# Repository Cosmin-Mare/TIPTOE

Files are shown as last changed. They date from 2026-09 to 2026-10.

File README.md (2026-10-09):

# TIPTOE

Multi-unit outdoor surveillance system with motion detection, night vision and long-range radio. Waterproof nodes watch an area, report events to a handheld over LoRa, and the handheld passes them to your phone.

One custom PCB for every unit · ESP32-S3 firmware (C++, PlatformIO) · Flutter companion app

| | |
|---|---|
| Hardware | [`PCB/`](PCB) schematics and gerbers, [`case/`](case) print files |
| Firmware and app | [`code/`](code) |
| Install the app | [Release v1.0.0](https://github.com/Cosmin-Mare/TIPTOE/releases/tag/v1.0.0) |
| Design log | [`JOURNAL.md`](JOURNAL.md) |

Top Right
Top Right white nocase

tiptoe_schematics_v5

## Overview

TIPTOE is a custom surveillance device built around the ESP32-S3. Units are deployed indoors or outdoors and talk to each other over LoRa for range and ESP-NOW when they're close. One unit is carried as a handheld; it collects events from the nodes and connects to a phone over BLE and Wi-Fi, where the app in [`code/app`](code/app) shows alerts and snapshots.

Every unit uses the same board. Whether it acts as a node or the handheld is set in firmware.

## Features

- **Motion detection** with a PIR sensor, which wakes the unit from sleep
- **Snapshots** from an OV3660 camera, with 940 nm IR LEDs for night vision
- **Audio** from a digital microphone
- **Qi wireless charging**, so the case can stay sealed, plus battery monitoring with a fuel gauge
- **Waterproof enclosure** for mounting on trees, walls or the ground (model in [`case/`](case))
- **No cloud or router needed:** unit-to-unit frames are AES-128-GCM encrypted and the phone link is passkey-paired BLE
- **Maintenance web page** on each node, with over-the-air firmware updates
- **App simulation mode**, so the whole flow can be tried without hardware

## Hardware

**Core**
- ESP32-S3-WROOM-1-N16R8 (main MCU)
- PCF8574T I/O expander (extra GPIO for peripherals)
**Power**
- BQ51013B Qi wireless receiver -> BQ25895 battery charger -> TPS63020 buck-boost -> ME6211 LDO
- MAX17048 fuel gauge for battery monitoring
**Sensing & I/O**
- OV3660 camera (DVP bus)
- ICS-43434 digital microphone
- HC-SR501 PIR motion sensor (boosted to 5V via AP3602AKTR-G1)
- IR LEDs for night vision (switched via AO3400A MOSFET)
- E22-900M22S LoRa module for long-range communication

## Project Status

The first PCB revision is in [`PCB/`](PCB), with firmware and the phone app in [`code/`](code). [`JOURNAL.md`](JOURNAL.md) was written in realtime throughout the design process and is left unpolished on purpose, so the raw process stays visible.

## Roadmap

- Assemble and test the first boards in person
- Finish the enclosure design and field-test it outdoors
- Publish a build write-up (Hack Club, Hackaday)

## Assembly

Getting from bare hardware to a running unit, end to end:

### 1. Fabricate & populate the board

- Gerbers: [`PCB/GERBER.zip`](PCB/GERBER.zip). Full BOM with LCSC part numbers: [`PCB/BOM.csv`](PCB/BOM.csv) (also below).
- Several parts are exposed-pad QFN/VQFN/WQFN packages (`BQ25895` WQFN-24, `TPS63020` VSON-14, `BQ51013B` VQFN-20, `MAX17048` TDFN-8) plus a 0.5 mm-pitch `ESP32-S3-WROOM-1` module and a 0.5 mm FPC camera connector — these need a stencil and reflow (or a hot-air rework station with real skill), not a hand iron alone. The straightforward path is to order PCB fab **and** SMT assembly together (e.g. JLCPCB PCBA) using the gerbers and the BOM/LCSC part numbers; leave through-hole parts (battery connector, PIR header, IR LEDs, buttons) for the assembly house to skip, and hand-solder those yourself afterward.
- You need at least 2 populated boards to test anything (one handheld + one node); the project targets 4 deployable units total. Every board is the *same* PCB — role is chosen later in firmware.

### 2. Connect the off-board modules

The BOM only places connectors on the PCB — three parts plug into those connectors and aren't optional for bring-up:

- **Camera** — an **OV3660** module, into the `Camera` FPC connector (`FPC-05F-24PH20`, 24-pin, 0.5mm pitch). Flip-lock connector: lift the tab, seat the FPC ribbon, press the tab back down.
- **PIR sensor** — an **HC-SR501** module, into the 3-pin `PIR` header (`HX PM2.54-1x3P`). Match GND/OUT/VCC to the silkscreen — it's a plain 2.54mm header, so it's easy to reverse.
- **Battery** — a single-cell Li-ion/LiPo pack terminated in a **JST-PH 2-pin** connector, into `BATTERY`. Mind polarity; the connector is keyed but double-check before first power-up. This is also how the board gets power to flash from, since USB-C is data-only (see below).

None of these three ship on the assembled board — order them separately and connect them before you flash.

### 3. Flash firmware

Each populated board runs the same firmware image. From [`code/`](code):

```bash
pip install platformio
cp src/common/secrets.example.h src/common/secrets.h     # then edit it
python3 -c "import os;print(', '.join('0x%02x'%b for b in os.urandom(16)))"   # paste into TIPTOE_NETWORK_KEY

pio run -t upload        # board must be running from battery or Qi (USB is data-only)
pio device monitor       # press a key within 3 s of boot for the console
```

- **USB-C is data-only by design** — the board must be powered from its battery or sitting on the Qi pad while you flash and use the console.
- From the console, set the role: `role handheld` on the unit you'll carry, `role node` (the default) on every outdoor unit. The unit reboots into the new role.
- Give each node a unique ID (`id 1`, `id 2`, …) from the console or its maintenance web UI.
- If a node is already asleep, hold BOOT, tap RST, release BOOT to force the ROM bootloader for the first flash. After that, firmware updates can go over Wi-Fi from the node's maintenance page.

Full firmware details, pin map, and console commands: [`code/README.md`](code/README.md).

### 4. First bring-up checklist

Run this on every board right after its first flash:

1. Power from battery, connect USB, reset, and press a key within 3 s → console.
2. `i2c` should list `0x20` (PCF8574), `0x36` (MAX17048), `0x6A` (BQ25895). The camera is on its own bus.
3. `selftest` checks the I/O expander, charger, fuel gauge, `VOUT` power-good, camera PID, mic level, IR pulse (watch through a phone camera — it's infrared), the SX1262 LoRa radio, flash, and PSRAM.
4. `status` shows charger state and the NTC reading; `chg` dumps the charger registers.
5. With the handheld powered on, `send` from a node should print `reply received`. `snap` runs a full event end-to-end.
6. `exit` → the node goes into normal sleep/wake operation.

### 5. Case & final assembly

- Case model: [`case/TIPTOE_Case.stp`](case/TIPTOE_Case.stp). Print or machine it, mount the populated PCB with the camera/PIR/IR LEDs aligned to the enclosure cutouts, and close it up for a node deployment.

### 6. Pair the app

- Install the app from [Release v1.0.0](https://github.com/Cosmin-Mare/TIPTOE/releases/tag/v1.0.0) (Android APK / iOS IPA), or run it from source — see [`code/app/README.md`](code/app/README.md).
- Pair with the handheld from the app. The BLE pairing PIN is `TIPTOE_BLE_PASSKEY`, set in the firmware's `secrets.h` — it isn't compiled into the app.
- No board yet? The app's first screen offers **Review with a simulation**, which walks through the whole flow without any hardware.

## Bill of Materials

Full sheet with LCSC links: [`PCB/BOM.csv`](PCB/BOM.csv).

| Qty | Designator(s) | Part / Value | LCSC # |
|---|---|---|---|
| 1 | 5VBoost | AP3602AKTR-G1 (PIR 5V boost) | [C460358](https://www.lcsc.com/product-detail/C460358.html) |
| 2 | ACM1, ACM2 | 22nF, C0603 | [C21122](https://www.lcsc.com/product-detail/C21122.html) |
| 1 | BATTERY | B2B-PH-K-S-GW (JST PH 2-pin) | [C5251182](https://www.lcsc.com/product-detail/C5251182.html) |
| 1 | Bat_Charger | BQ25895RTWT | [C2861263](https://www.lcsc.com/product-detail/C2861263.html) |
| 5 | BST1, BST2, C11, C12, C13 | 10nF, C0603 | [C100042](https://www.lcsc.com/product-detail/C100042.html) |
| 1 | Buck_Boost | TPS63020DSJR | [C15483](https://www.lcsc.com/product-detail/C15483.html) |
| 14 | C1, C5, C7, C15, C23, C25, C26, C27, C34, C36, C38, C39, DC1_ESP, DC2_ESP | 100nF, C0603 | [C14663](https://www.lcsc.com/product-detail/C14663.html) |
| 9 | C2, C3, C6, C9, C16, C17, C18, C21, C22 | 10uF, C1206 | [C9807](https://www.lcsc.com/product-detail/C9807.html) |
| 1 | C4 | 1nF, C0603 | [C106246](https://www.lcsc.com/product-detail/C106246.html) |
| 11 | C8, C19, C20, C24, C29, C30, C31, C32, C33, C35, C37 | 1uF, C1206 | [C90539](https://www.lcsc.com/product-detail/C90539.html) |
| 1 | C10 | 4.7uF, C1206 | [C29823](https://www.lcsc.com/product-detail/C29823.html) |
| 1 | C14 | 22uF, C1206 | [C5448922](https://www.lcsc.com/product-detail/C5448922.html) |
| 1 | C28 | 820pF, C0603 | [C107057](https://www.lcsc.com/product-detail/C107057.html) |
| 1 | Camera | FPC-05F-24PH20 (0.5mm 24P FPC) | [C2856805](https://www.lcsc.com/product-detail/C2856805.html) |
| 2 | CAM_SCL_PU, CAM_SDA_PU | 4.7kΩ, R0603 | [C23162](https://www.lcsc.com/product-detail/C23162.html) |
| 2 | CLAMP1, CLAMP2 | 470nF, C0603 | [C513577](https://www.lcsc.com/product-detail/C513577.html) |
| 1 | ESP | ESP32-S3-WROOM-1-N16R8 | [C2913202](https://www.lcsc.com/product-detail/C2913202.html) |
| 1 | Fuel_Gauge | MAX17048G+T10 | [C2682616](https://www.lcsc.com/product-detail/C2682616.html) |
| 2 | IO0, RST | TSD001A07526A (tactile button) | [C2888886](https://www.lcsc.com/product-detail/C2888886.html) |
| 1 | IOExpander | PCF8574T/TR | [C2987288](https://www.lcsc.com/product-detail/C2987288.html) |
| 4 | IR1, IR2, IR3, IR4 | IR333C-A (940nm IR LED) | [C5130](https://www.lcsc.com/product-detail/C5130.html) |
| 2 | L1, L2 | 2.2uH inductor | [C76855](https://www.lcsc.com/product-detail/C76855.html) |
| 1 | L3 | GZ1608D601TF (ferrite bead) | [C1002](https://www.lcsc.com/product-detail/C1002.html) |
| 1 | LORA | E22-900M22S (SX1262 LoRa module) | [C411293](https://www.lcsc.com/product-detail/C411293.html) |
| 1 | MIC | ICS-43434 (digital mic) | [C5656610](https://www.lcsc.com/product-detail/C5656610.html) |
| 1 | MSF_IR | AO3400A (IR LED MOSFET) | [C49195711](https://www.lcsc.com/product-detail/C49195711.html) |
| 1 | NTC | NCP18XH103F03RB (10k NTC) | [C13564](https://www.lcsc.com/product-detail/C13564.html) |
| 4 | PD_MSF, R11, R14, R18 | 100kΩ, R0603 | [C25803](https://www.lcsc.com/product-detail/C25803.html) |
| 1 | PIR | HX PM2.54-1x3P (PIR header) | [C22438153](https://www.lcsc.com/product-detail/C22438153.html) |
| 1 | QiCoil | 15uH Qi coil | [C3003210](https://www.lcsc.com/product-detail/C3003210.html) |
| 1 | QIPowerRec | BQ51013BRHLR | [C55663](https://www.lcsc.com/product-detail/C55663.html) |
| 11 | R1, R5, R6, R7, R8, R15, R16, R17, R21, RESETB_PU, R_IO0 | 10kΩ, R0603 | [C25804](https://www.lcsc.com/product-detail/C25804.html) |
| 4 | R2, R4, R9, R10 | 33Ω, R1206 | [C102174](https://www.lcsc.com/product-detail/C102174.html) |
| 1 | R3 | 68Ω, R0603 | [C27592](https://www.lcsc.com/product-detail/C27592.html) |
| 1 | R12 | 560kΩ, R0603 | [C23203](https://www.lcsc.com/product-detail/C23203.html) |
| 3 | R20, R24, R25 | 100Ω, R0603 | [C22775](https://www.lcsc.com/product-detail/C22775.html) |
| 1 | R22 | 470Ω, R0603 | [C23179](https://www.lcsc.com/product-detail/C23179.html) |
| 2 | R, R13 | 1kΩ, R0603 | [C126900](https://www.lcsc.com/product-detail/C126900.html) |
| 1 | RT1 | 5.1kΩ, R0603 | [C23186](https://www.lcsc.com/product-detail/C23186.html) |
| 1 | RT2 | 30kΩ, R0603 | [C100945](https://www.lcsc.com/product-detail/C100945.html) |
| 2 | R_CC5, R_CC6 | 5.1kΩ, R0402 | [C25905](https://www.lcsc.com/product-detail/C25905.html) |
| 2 | R_CC7, R_CC8 | 22Ω, R0402 | [C25092](https://www.lcsc.com/product-detail/C25092.html) |
| 1 | U4 | 47nF, C0805 | [C107154](https://www.lcsc.com/product-detail/C107154.html) |
| 1 | USBC | TYPE-C-31-M-12 (USB-C receptacle) | [C165948](https://www.lcsc.com/product-detail/C165948.html) |
| 1 | Voltage_Reg | ME6211C33M5G-N (3.3V LDO) | [C82942](https://www.lcsc.com/product-detail/C82942.html) |
| 1 | Voltage_Reg1.5V | TPLP5907MFX-1.5 (1.5V LDO, camera DVDD) | [C49451987](https://www.lcsc.com/product-detail/C49451987.html) |
| 1 | Voltage_Reg2.8V | LP5907MFX-2.8/NOPB (2.8V LDO, camera AVDD/DOVDD) | [C186700](https://www.lcsc.com/product-detail/C186700.html) |

Not on this sheet but needed to build a unit: an **HC-SR501 PIR module** and an **OV3660 camera module** (both connect via headers/FPC rather than being placed on the board), plus a single-cell Li-ion/LiPo battery with a JST-PH connector.

## Repo contents
- [`code/`](code) — firmware (`src/`), phone app (`app/`), and how to flash or run the simulation
- [`PCB/`](PCB) — `BOM.csv`, `TIPTOE_easyEDA.epro2`, `GERBER.zip`
- [`case/`](case) — `TIPTOE_Case.stp`
- [`JOURNAL.md`](JOURNAL.md) — dated build log, including time spent and screenshots

---

Designed and built by [Cosmin Mare](https://mare-cosmin.ro/en/).

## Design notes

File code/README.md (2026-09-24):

# TIPTOE code

Firmware for the rev1 board, and the phone app that talks only to the handheld.

| | |
|---|---|
| **Firmware** | [Below](#firmware). One image for every unit. Build and flash from this folder with PlatformIO. |
| **Phone app** | [app/README.md](app/README.md). From `app/`, run `flutter run`. The first screen can **Review with a simulation** without a board. |
| **Install** | [Release v1.0.0](https://github.com/Cosmin-Mare/TIPTOE/releases/tag/v1.0.0) — Android APK and iOS IPA. |

## Firmware

One firmware image for every TIPTOE unit (rev1 PCB, `Netlist_Schematic1_2026-09-23.net`). Each unit runs in one of two roles:

- **node** (default): outdoor unit. Sleeps, wakes on motion, takes a photo and a sound sample, and reports to the handheld.
- **handheld**: the unit you carry. Stays awake, collects everything from the nodes, and serves your phone app over **BLE** (always) and **Wi-Fi** (on demand).

```
outdoor nodes ──LoRa 869.525 MHz (always) ─────────────────┐
              ──ESP-NOW (when near + handheld Wi-Fi is on)─┴─▶ handheld ──BLE / Wi-Fi AP──▶ phone app
```

No cloud, no router, no Home Assistant. Unit-to-unit frames are AES-128-GCM encrypted, and the BLE link is passkey-paired. The app-facing API is in **[docs/APP_PROTOCOL.md](docs/APP_PROTOCOL.md)**.

Set the role from the USB console: `role handheld` or `role node`. The unit reboots into the new role.

## Node role

The node spends almost all its time in deep sleep. Each wake does one job and goes back to sleep:

| Wake source | What happens |
|---|---|
| **PIR** (IO3, ext0) | VOUT on → OV3660 capture (auto IR from measured scene brightness) with the ICS-43434 recording at the same time → saves JPEG + full-res JPEG + WAV to flash → if the handheld recently said its Wi-Fi is on, sends the **full-res** photo over **ESP-NOW**; otherwise (or if that fails) the small photo over **LoRa** with selective-repeat retransmission → processes any commands in the reply. |
| **Timer** | Heartbeat status over LoRa (battery, charger, Qi input, temperature, RSSI, config). Commands queued on the handheld come down in the reply window. |
| **BOOT button** (IO0, ext1) | Maintenance mode: Wi-Fi AP `TIPTOE-<id>` with a web UI at `http://192.168.4.1/` (status, event archive with photos/audio, live snapshot ± IR, config, OTA firmware upload). Press the button again or leave it idle for 10 min to exit. |
| **Cold boot / reset** | 3 s window to open the USB console (press any key), then a HELLO uplink to the handheld. The PIR is ignored for the first 60 s while it warms up. |

Other behaviour:
- **Cooldown** (default 30 s). Motion during cooldown sends a header-only event, at most every 10 s. If the PIR is still high when the node goes to sleep, it re-checks every 5 s, so continuous motion keeps producing events.
- **Duty cycle.** Sub-band g3 (869.4–869.65 MHz) allows 10 % duty cycle at ≤500 mW ERP. The node tracks its airtime in RTC memory and caps itself at 300 s per hour. If an image won't fit in what's left, it's kept locally and the event goes out flagged `no_budget`.
- **Battery.** Below 15 % the node skips the full-res photo and the audio. Below 5 % (and not charging) it stops arming the PIR and sends a heartbeat every 3 h at most.
- **Security.** Every frame is AES-128-GCM with an 8-byte tag. The frame counter is persisted in blocks, so a power loss never repeats a nonce. The handheld rejects old counters, and the node only accepts a downlink that echoes the uplink it just sent.
- **Watchdog.** 90 s. A hung camera, radio or I2C bus can't keep the node awake and drain the battery.

### Pin map (from the netlist)

| Function | Pin |
|---|---|
| Main I2C SDA / SCL (PCF8574 0x20, MAX17048 0x36, BQ25895 0x6A) | IO8 / IO9 |
| Camera SCCB SDA / SCL (OV3660 0x3C, own bus, 1k series + 4.7k to CAM 2.8V) | IO43 (TXD0) / IO44 (RXD0) |
| TPS63020 EN (VOUT → camera 2.8 V / 1.5 V LDOs, mic, IR LED anodes) | IO2 |
| PIR out | IO3 |
| SX1262 MOSI/MISO/SCK/NSS/BUSY/DIO1 | IO10/11/12/13/14/21 |
| SX1262 NRST / RXEN / TXEN | PCF8574 P4 / P5 / P6 |
| IR LED MOSFET gate | PCF8574 P2 |
| TPS63020 PG / MAX17048 ALRT | PCF8574 P3 / P0 |
| PCF8574 INT# | IO38 |
| Mic SCK / WS / SD | IO1 / IO47 / IO48 |
| Camera XCLK, PCLK, VSYNC, HREF | IO39, IO16, IO42, IO41 |
| Camera D9..D2 | IO40, 18, 17, 15, 6, 4, 5, 7 |

The SX1262's RF-switch and reset lines sit on the PCF8574. A small RadioLib HAL subclass (`src/node/link.cpp`) maps "virtual" pins to the expander, so RadioLib drives them transparently.

## Hardware notes (rev1, 2026-09-23 netlist)

Fixed during the schematic review:
- **Charger temperature sensing.** The BQ25895's TS pin (the battery-temperature input) now has RT1 5.1k (REGN→TS), RT2 30k and a 10k NCP18 NTC. Charging runs from about 2 °C to 41 °C. Place the NTC against the cell, away from the charger, the inductors and the Qi coil.
- **Camera power.** AVDD comes from `CAM 2.8V` through a ferrite bead, DOVDD from `CAM 2.8V`, DVDD from `CAM 1.5V` (both LP5907-type LDOs fed from VOUT), and AGND is grounded. RESETB is pulled up to `CAM 2.8V` with an RC delay.
- **Camera I2C (SCCB).** It's on its own pins (GPIO43/44) with pull-ups to `CAM 2.8V`, so the main I2C bus is never loaded by an unpowered camera. **Keep the 1k series resistors between the ESP and the camera:** GPIO43 is UART0 TX, and the boot ROM drives it on every wake. The firmware releases GPIO43/44 to inputs as its first action.
- **IR LEDs.** The resistors are 33 Ω 1206, about 58 mA per LED (roughly 3× the light of the original 100 Ω).

By design:
- **USB-C VBUS isn't connected.** USB is data-only, so flash and use the console while the board runs from its battery or sits on the Qi pad. A flat battery recovers on the Qi pad, because the charger works without firmware. After the first flash, use Wi-Fi OTA from the maintenance page.

Minor points:
- PCF8574 INT# is on IO38, which isn't an RTC pin, so a fuel-gauge alert can't wake the chip. The firmware polls instead.
- The PCF8574 powers up with all pins high, so RXEN and TXEN are both high for a few ms until the firmware writes the defaults. This is harmless because the radio isn't transmitting.
- The mic is an **ICS-43434**. The firmware picks the live I2S slot automatically.

## Build and flash

```bash
pip install platformio
cp src/common/secrets.example.h src/common/secrets.h     # then edit it
python3 -c "import os;print(', '.join('0x%02x'%b for b in os.urandom(16)))"   # paste into TIPTOE_NETWORK_KEY

pio run -t upload        # board must be running from battery or Qi (USB is data-only)
pio device monitor       # press a key within 3 s of boot for the console; `role handheld` on the one you carry
```

If the node is already in deep sleep, hold BOOT, tap RST, release BOOT to enter the ROM bootloader. After the first flash you can also update over Wi-Fi from the maintenance page (upload `.pio/build/tiptoe/firmware.bin`).

**Give each node a unique ID.** The default comes from the MAC address's last byte. Set it explicitly from the console (`id 1`, `id 2`, …) or the web UI.

### First bring-up checklist

1. Power from battery, connect USB, reset, and press a key within 3 s → console.
2. `i2c` should list 0x20, 0x36 and 0x6A. The camera is on its own bus, so `selftest` checks it separately.
3. `selftest` checks the expander, charger, gauge, VOUT PG, camera PID, mic level, IR pulse (watch through a phone camera), SX1262, flash and PSRAM.
4. `status` shows the charger state and the NTC reading, and `chg` dumps the charger registers.
5. With the handheld running, `send` should print "reply received". `snap` runs a full event end to end.
6. `exit` → the node goes into normal sleep/wake operation.

## Handheld role

The handheld is the same PCB. It doesn't use the PIR, camera or mic, and it never deep-sleeps.

- **LoRa listens all the time.** The handheld receives node status, events and photos, and answers with the time plus any queued commands.
- **It keeps an archive** in its 9.8 MB of flash: every event's metadata plus the photo (LoRa small, or ESP-NOW full-res). The oldest entries are pruned automatically.
- **BLE (`TIPTOE-HH`)** pairs once with a passkey. It pushes motion alerts, status and small photos to the phone the moment they arrive, and accepts commands for any node. A command waits on the handheld until that node next checks in.
- **Wi-Fi comes on only when asked**, from the app or with the BOOT button. The access point `TIPTOE-HH` serves an HTTP API for fast archive and full-res downloads. While it's on, the handheld's replies tell nearby nodes to push full-res photos over ESP-NOW. It turns off after 10 minutes of inactivity.
- **Low battery:** below 3 % (and not charging) it warns the app and powers down. Press BOOT to wake it.
- **Estimated battery life:** ~30–40 mA with BLE + LoRa, so about 2–3 days on a 2000 mAh cell. Wi-Fi adds ~100 mA while it's on. These are estimates, to be measured on the real board.

## Tuning

| Setting | Default | Notes |
|---|---|---|
| `protocol.h` `SF` | 7 | A QVGA JPEG (~6 KB, ~30 chunks) takes ~12 s of airtime. SF9 has more range but ~4× the airtime. Every unit must match. |
| `framesize` / `jpeg_quality` | QVGA / 14 | This is the LoRa image. The full-res copy (2048×1536) stays in flash. |
| `ir_mode` / `ir_luma` | auto / 40 | IR turns on when the probe frame's mean luma is below the threshold, and the sensor switches to grayscale. |
| `TIPTOE_CHARGE_MA` | 512 | Keep at ≤0.5 C of your cell. |
| `TIPTOE_VREG_MV` | 4208 | 4100 is kinder to a cell sitting in the sun. |
| `TIPTOE_CAM_VFLIP/HMIRROR` | 1/0 | Match the camera's orientation in the enclosure. |

Build-time defines go in `build_flags`, and runtime settings go through the app (via the handheld), the console `set`, or a node's maintenance web UI.

## Layout

```
src/common/   protocol.h/.cpp (unit-to-unit frame format, AES-GCM), secrets.example.h
src/tiptoe/   main.cpp (role dispatch, node wake/sleep), board.h (pin map)
              node:     app.cpp (event/status logic), camera, audio, link (LoRa), espnow_link,
                        maintenance (walk-up Wi-Fi web UI + OTA)
              handheld: handheld.cpp (node table, archive, command queue, app API),
                        hh_ble.cpp (BLE service), hh_wifi.cpp (AP, HTTP, ESP-NOW RX)
              shared:   power (BQ25895/MAX17048/VOUT), expander (PCF8574), storage (LittleFS),
                        config (NVS), console (USB bench CLI + selftest)
docs/         APP_PROTOCOL.md — BLE/HTTP API for the phone app
app/          Flutter phone app. See app/README.md and APP_GUIDE.md
```

What's verified: it compiles against Arduino-ESP32 2.0.17, RadioLib 7.7 and NimBLE-Arduino 1.4, and the frame encryption was round-trip and tamper tested on a PC. Nothing has run on the real board yet.

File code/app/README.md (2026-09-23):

# TIPTOE phone app

Flutter app for the handheld side of the TIPTOE PCB. Outdoor nodes are never contacted directly, except in walk-up maintenance mode. Behaviour and screens follow `APP_GUIDE.md`. The byte format follows `docs/APP_PROTOCOL.md`.

## Layout

```
lib/
  protocol/    BLE framing and JSON messages
  domain/      online/offline, health warnings, command ETAs
  data/        SQLite archive and JPEG files
  link/        BLE, simulated handheld, Wi-Fi join, HTTP
  services/    HandheldService (the only BLE owner) and notifications
  state/       the store screens read
  ui/          theme and shared widgets
  features/    onboarding, home, map, timeline, event, node, handheld, settings, simulation, maintenance
```

Screens call the store. The store calls `HandheldService`. The service owns the connection, the stream parser, and command matching.

## Review without a board

The first screen offers **Review with a simulation**. It is available in release builds, so someone reviewing the app does not need a PCB or a debug flag.

The simulation speaks the same framed protocol as the handheld. Suggested node names are Garden, Gate, and Shed. A guide then walks through:

- an online node, a late node, and an offline node with health warnings
- a map centered on the phone, where each camera can be placed and a motion alert turns its pin red
- a motion alert, then the photo a couple of seconds later
- a setting that stays pending until the node’s next check-in
- a camera failure and a duty-cycle limit
- Near mode, then fetching the full-resolution photo over Bluetooth

Leave the simulation from that guide or from Settings to pair a real handheld.

```bash
cd app
flutter run
```

## Run with the handheld

1. Flash a unit and set `role handheld` from the USB console.
2. Pair when the phone asks. The 6-digit PIN is `TIPTOE_BLE_PASSKEY` in the firmware's `secrets.h`. It is not compiled into the app.
3. Name the nodes. Names stay on the phone.

Full-resolution downloads join the `TIPTOE-HH` network from the `wifi` message, fetch `http://192.168.4.1/img`, then turn Wi-Fi off. On iOS this needs the Hotspot Configuration capability (`com.apple.developer.networking.HotspotConfiguration`) on the app identifier. Android binds the process to that network so mobile data can stay up.

Node maintenance (`Visit node`) uses `TIPTOE-<id>` and the maintenance password from firmware secrets.

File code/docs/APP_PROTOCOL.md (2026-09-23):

# TIPTOE handheld ↔ app protocol

The phone only ever talks to the **handheld**: a TIPTOE unit set to `role handheld`. The handheld listens to the outdoor nodes over LoRa (and ESP-NOW when its Wi-Fi is on), keeps an archive, and exposes it over:

- **BLE**, always on: live alerts, status, small photos, commands.
- **Wi-Fi access point**, on demand: fast HTTP access to the archive and full-resolution photos.

```
outdoor nodes ──LoRa (always) / ESP-NOW (when near + handheld Wi-Fi on)──▶ handheld ──BLE / Wi-Fi──▶ phone app
```

## 1. BLE

| | UUID |
|---|---|
| Service | `7a1e0001-5c1d-4b8e-9f00-7469707430e0` |
| RX, the app **writes** commands | `7a1e0002-5c1d-4b8e-9f00-7469707430e0` |
| TX, the app **subscribes** to notifications | `7a1e0003-5c1d-4b8e-9f00-7469707430e0` |

The device advertises as **`TIPTOE-HH`**, with the service UUID in the advertisement, so you can scan with a service filter.

### Connecting

1. Connect, then **request MTU 517**. Android needs `requestMTU(517)`; iOS negotiates by itself.
2. The handheld starts pairing right away. The phone asks for a **6-digit passkey** (`TIPTOE_BLE_PASSKEY` in `secrets.h`). After that the bond is remembered.
3. Subscribe to TX notifications.
4. The handheld then sends `handheld`, `nodes` and `wifi` messages on its own. Send `{"cmd":"time","unix":<now>}` straight away. This is the only time source in the system: the handheld passes it on to every node.

Nothing is sent, and no command is accepted, until the link is encrypted and authenticated.

In React Native, `react-native-ble-plx` handles all of this. Values are base64 in that library.

### TX stream framing (handheld → app)

Treat the notifications as **one continuous byte stream**. Append each notification's bytes to a buffer and cut frames out of it:

```
[type: u8][length: u32 little-endian][payload: length bytes]
```

| type | payload |
|---|---|
| `1` | UTF-8 JSON object (see §3) |
| `2` | Image: `[seq: u32 LE][full: u8][JPEG bytes…]` |

A frame can span many notifications, and one notification can contain the end of one frame and the start of the next. Notifications arrive in order and reliably, so a simple buffer-and-parse loop is enough.

### RX (app → handheld)

Write **one JSON command per write** (≤ 512 bytes), using write-with-response. Every command may carry a `"rid"` (any number or string), which is echoed back in the response so you can match them up.

## 2. Commands

| Command | Example | Response |
|---|---|---|
| `hello` / `nodes` | `{"cmd":"nodes"}` | `nodes` message |
| `handheld` | `{"cmd":"handheld"}` | `handheld` message |
| `time` | `{"cmd":"time","unix":1758630000}` | `{"t":"resp","cmd":"time","ok":true}` |
| `events` | `{"cmd":"events","node":3,"limit":20,"before":120}` | `events` message. `node` 0 or omitted = all nodes; `before` = page by seq |
| `get_image` | `{"cmd":"get_image","seq":57,"full":true}` | `resp` with `bytes`, then a **type-2 frame** with the JPEG. `full:true` falls back to the small photo if no full-res one exists |
| `delete_event` | `{"cmd":"delete_event","seq":57}` | `resp` |
| `set` | `{"cmd":"set","node":3,"key":"armed","value":0}` | `resp` with `queued_for` |
| `snapshot` | `{"cmd":"snapshot","node":3}` | `resp` with `queued_for` |
| `status` | `{"cmd":"status","node":3}` | node sends a fresh status |
| `reboot` | `{"cmd":"reboot","node":3}` | |
| `maintenance` | `{"cmd":"maintenance","node":3}` | node opens its own Wi-Fi AP `TIPTOE-<id>` (walk-up setup / OTA) |
| `clear` | `{"cmd":"clear","node":3}` | node wipes its local archive |
| `cancel` | `{"cmd":"cancel","node":3}` | drops commands still queued for that node |
| `wifi` | `{"cmd":"wifi","on":true}` | `wifi` message with the credentials |

`"node": 0` means **all known nodes**.

**Node commands are queued.** Outdoor nodes sleep, so a command waits on the handheld and is delivered in the reply to that node's next transmission: its heartbeat (default every 30 min, `heartbeat_min`) or its next event. The `pending` message tells you what's still waiting. For quicker delivery, lower `heartbeat_min`; it costs a little battery on the node.

Keys for `set`:

| key | range | meaning |
|---|---|---|
| `armed` | 0/1 | PIR events on/off |
| `heartbeat_min` | 1–1440 | status interval |
| `cooldown_s` | 0–3600 | min seconds between photo events |
| `jpeg_quality` | 4–63 | LoRa photo quality (lower = better/bigger) |
| `framesize` | 0–10 | LoRa photo size (esp32-camera framesize; 5 = QVGA 320×240, 8 = VGA, 10 = XGA). Larger sizes are rejected |
| `ir_mode` | 0/1/2 | IR off / always / auto |
| `ir_luma` | 0–255 | auto-IR brightness threshold |
| `audio_ms` | 0–5000 | sound sample length per event |
| `tx_power` | -9–22 | LoRa dBm |
| `send_image` | 0/1 | send photos at all |
| `hires_local` | 0/1 | node keeps a full-res copy in its own flash |
| `grayscale_ir` | 0/1 | B/W when IR is on |

## 3. Messages (handheld → app)

Every JSON message has a `"t"` field.

**`event`**: the motion alert. It's sent the moment the node's event header arrives, before any image data.
```json
{"t":"event","node":3,"event_id":41,"trigger":"pir","time":1758630123,"ir":true,"camera_failed":false,
 "no_budget":false,"hires_on_node":true,"sound_peak_db":-23,"sound_rms_db":-41,"luma":18,"soc":76,
 "width":2048,"height":1536,"img_len":231904,"via":"espnow","rssi":0,"incoming_image":true}
```

**`image`**: an event was archived; `seq` is its id in the handheld archive. For LoRa photos (`full:false`, ≤ 64 KB) a **type-2 frame with the JPEG follows automatically**. Full-res ESP-NOW photos are not pushed: fetch them with `get_image` over BLE (slow) or over HTTP with Wi-Fi on (fast).
```json
{"t":"image","seq":57,"node":3,"event_id":41,"trigger":"pir","time":1758630123,"received":1758630131,
 "via":"lora","rssi":-97.5,"image":true,"full":false,"bytes":6123, "...event fields..."}
```

**`status`** / **`hello_node`**: a node's heartbeat, or its first message after a power-up. `rssi`/`snr` are measured at the handheld (LoRa).
```json
{"t":"status","node":3,"reason":4,"rssi":-101,"snr":6.5,"via":"lora",
 "status":{"fw":"1.2","armed":1,"soc":76.4,"vbat_mv":3981,"crate_pct_h":-0.4,"charge":"not charging",
           "ntc":"normal","charger_fault":0,"qi_mv":0,"temp_c":21,"node_rssi":-95,"event_count":12,
           "uptime_s":86400,"fs_free_kb":8120,"hw_ok":127,
           "config":{"armed":1,"heartbeat_min":30,"cooldown_s":30,"jpeg_quality":14,"framesize":5,"ir_mode":2,"ir_luma":40,"audio_ms":1500,"tx_power":22,"send_image":1,"hires_local":1,"grayscale_ir":1}}}
```
`hw_ok` bits: 1 expander, 2 charger, 4 fuel gauge, 8 camera, 16 mic, 32 camera power rail, 64 flash.

**`nodes`**: every node the handheld knows about.
```json
{"t":"nodes","nodes":[{"node":3,"age_s":412,"rssi":-101,"snr":6.5,"via":"lora","pending":0,"status":{...}}]}
```

**`events`**: archive page, newest first. Each entry has the same fields as `image`.

**`pending`**: `{"t":"pending","node":3,"count":1}`

**`handheld`**: the handheld's own state, sent on connect and every 60 s.
```json
{"t":"handheld","fw":"1.2","soc":88.1,"vbat_mv":4052,"charge":"not charging","ntc":"normal","wifi":false,
 "time_synced":true,"uptime_s":5321,"fs_free_kb":9400,"lora_budget_ms":298211,"lora_ok":true}
```

**`wifi`**: `{"t":"wifi","on":true,"ssid":"TIPTOE-HH","pass":"…","ip":"192.168.4.1","port":80,"channel":1}`

**`resp`**: `{"t":"resp","cmd":"set","ok":true,"queued_for":1,"rid":7}`

**`warning`**: e.g. handheld battery critical, just before it powers down.

## 4. Wi-Fi (on demand)

Send `{"cmd":"wifi","on":true}` over BLE, or press the handheld's BOOT button. You get a `wifi` message with the SSID and password. Join that network from the app:
- Android: `WifiNetworkSpecifier` / `react-native-wifi-reborn` `connectToProtectedSSID`. Android keeps mobile data for the internet.
- iOS: `NEHotspotConfiguration`.

While Wi-Fi is on, nodes near the handheld send their **full-res photos over ESP-NOW** (`via:"espnow"`, `full:true`) instead of the small LoRa version. Wi-Fi turns itself off after 10 minutes without activity, or when you send `{"cmd":"wifi","on":false}`. Leave it off normally, because it costs the handheld about 100 mA.

HTTP API at `http://192.168.4.1`:

| | |
|---|---|
| `GET /api/nodes` | same as the `nodes` message |
| `GET /api/handheld` | same as the `handheld` message |
| `GET /api/events?node=3&limit=50&before=120` | same as the `events` message |
| `GET /img?seq=57&full=1` | JPEG |
| `POST /api/cmd` (body = command JSON) | same commands as BLE (`get_image` returns a `url` instead of pushing bytes) |

## 5. Things to design the app around

- **Latency.**
  - Motion alerts reach the phone within a second or two of the PIR firing, over LoRa or ESP-NOW.
  - A LoRa photo (~6 KB) needs ~10–15 s more.
  - A full-res ESP-NOW photo needs a few seconds.
- **The handheld is the archive.** The phone can be disconnected and catch up later with `events` + `get_image`. Each node also keeps its own full-res photos and audio; you get at those with the node's maintenance mode.
- **Battery estimates** (rough, to be measured):
  - Handheld: about 30–40 mA with BLE + LoRa listening, so ~2–3 days on a 2000 mAh cell; with Wi-Fi on, about +100 mA.
  - Nodes: weeks to months, depending on how many events they record.

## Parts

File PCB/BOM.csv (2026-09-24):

No. | Quantity | Comment | Designator | Footprint | Value | Manufacturer Part | Manufacturer | Supplier Part | Supplier | LCSC Part Name | LCSC Price | LCSC Link
1 | 1 | AP3602AKTR-G1 | 5VBoost | SOT-23-6_L2.9-W1.6-P0.95-LS2.8-BR |  | AP3602AKTR-G1 | DIODES(美台) | C460358 | LCSC | 100mA 稳压电荷泵 |  | https://www.lcsc.com/product-detail/C460358.html
2 | 2 | 22nF | ACM1,ACM2 | C0603 | 22nF | CL10B223KB8NNNC | SAMSUNG(三星) | C21122 | LCSC | 22nF ±10% 50V |  | https://www.lcsc.com/product-detail/C21122.html
3 | 1 | B2B-PH-K-S-GW | BATTERY | CONN-TH_B2B-PH-K-S |  | B2B-PH-K-S-GW | JST | C5251182 | LCSC | 1x2P 间距:2mm 直插 系列:PH |  | https://www.lcsc.com/product-detail/C5251182.html
4 | 1 | BQ25895RTWT | Bat_Charger | WQFN-24_L4.0-W4.0-P0.50-TL-EP2.7 |  | BQ25895RTWT | TI(德州仪器) | C2861263 | LCSC | I2C控制单节5A快速充电器（采用MaxCharge技术实现高输入电压和可调电压3.1A升压操作） |  | https://www.lcsc.com/product-detail/C2861263.html
5 | 5 | 10nF | BST1,BST2,C11,C12,C13 | C0603 | 10nF | CC0603KRX7R9BB103 | YAGEO(国巨) | C100042 | LCSC | 10nF ±10% 50V |  | https://www.lcsc.com/product-detail/C100042.html
6 | 1 | TPS63020DSJR | Buck_Boost | VSON-14_L4.0-W3.0-P0.50-BL-EP_TI_DSJ |  | TPS63020DSJR | TI(德州仪器) | C15483 | LCSC | 高效率单电感升降压转换器 |  | https://www.lcsc.com/product-detail/C15483.html
7 | 14 | 100nF | C1,C5,C7,C15,C23,C25,C26,C27,C34,C36,C38,C39,DC1_ESP,DC2_ESP | C0603 | 100nF | CC0603KRX7R9BB104 | YAGEO(国巨) | C14663 | LCSC | 100nF ±10% 50V |  | https://www.lcsc.com/product-detail/C14663.html
8 | 9 | 10uF | C2,C3,C6,C9,C16,C17,C18,C21,C22 | C1206 | 10uF | CL31A106KAHNNNE | SAMSUNG(三星) | C9807 | LCSC | 10uF ±10% 25V |  | https://www.lcsc.com/product-detail/C9807.html
9 | 1 | 1nF | C4 | C0603 | 1nF | CC0603JRNPO9BN102 | YAGEO(国巨) | C106246 | LCSC | 1nF ±5% 50V |  | https://www.lcsc.com/product-detail/C106246.html
10 | 11 | 1uF | C8,C19,C20,C24,C29,C30,C31,C32,C33,C35,C37 | C1206 | 1uF | 1206B105K500NT | FH(风华) | C90539 | LCSC | 1uF ±10% 50V |  | https://www.lcsc.com/product-detail/C90539.html
11 | 1 | 4.7uF | C10 | C1206 | 4.7uF | 1206B475K500NT | FH(风华) | C29823 | LCSC | 4.7uF ±10% 50V |  | https://www.lcsc.com/product-detail/C29823.html
12 | 1 | 22uF | C14 | C1206 | 22uF | TCC1206X5R226K250HT | CCTC(三环) | C5448922 | LCSC | 22uF ±10% 25V |  | https://www.lcsc.com/product-detail/C5448922.html
13 | 1 | 820pF | C28 | C0603 | 820pF | CC0603JRNPO9BN821 | YAGEO(国巨) | C107057 | LCSC | 820pF ±5% 50V |  | https://www.lcsc.com/product-detail/C107057.html
14 | 1 | FPC-05F-24PH20 | Camera | FPC-SMD_24P-P0.50_FPC-05F-24PH20 |  | FPC-05F-24PH20 | XUNPU(讯普) | C2856805 | LCSC | 翻盖式 下接 P数:24P 间距:0.5mm |  | https://www.lcsc.com/product-detail/C2856805.html
15 | 2 | 4.7kΩ | CAM_SCL_PU,CAM_SDA_PU | R0603 | 4.7kΩ | 0603WAF4701T5E | UNI-ROYAL(厚声) | C23162 | LCSC | 厚膜电阻 4.7kΩ ±1% |  | https://www.lcsc.com/product-detail/C23162.html
16 | 2 | 470nF | CLAMP1,CLAMP2 | C0603 | 470nF | CC0603KRX7R9BB474 | YAGEO(国巨) | C513577 | LCSC | 470nF ±10% 50V |  | https://www.lcsc.com/product-detail/C513577.html
17 | 1 | 2.4GHz | ESP | WIRELM-SMD_ESP32-S3-WROOM-1 | 2.4GHz | ESP32-S3-WROOM-1-N16R8 | ESPRESSIF(乐鑫) | C2913202 | LCSC | 不带固件 通用型Wi-Fi+低功耗蓝牙MCU模组 |  | https://www.lcsc.com/product-detail/C2913202.html
18 | 1 | MAX17048G+T10 | Fuel_Gauge | TDFN-8_L2.0-W2.0-P0.50-BL-EP1.2 |  | MAX17048G+T10 | ADI(亚德诺)/MAXIM(美信) | C2682616 | LCSC | 3uA单节/双节电池电量计，带ModelGauge算法 |  | https://www.lcsc.com/product-detail/C2682616.html
19 | 2 | TSD001A07526A | IO0,RST | SW-TH_4P-L6.0-W6.0-P4.50-LS6.3 |  | TSD001A07526A | BZCN(博众电气) | C2888886 | LCSC | 6*6*7.5H-JZ 260gf |  | https://www.lcsc.com/product-detail/C2888886.html
20 | 1 | PCF8574T/TR | IOExpander | SO-16_L10.3-W7.5-P1.27-LS10.3-BL |  | PCF8574T/TR | HGSEMI(华冠) | C2987288 | LCSC | 远程8位I2C总线I/O扩展器 |  | https://www.lcsc.com/product-detail/C2987288.html
21 | 4 | IR333C-A | IR1,IR2,IR3,IR4 | LED-TH_BD5.9-P2.54-RD_WHITE |  | IR333C-A | EVERLIGHT(亿光) | C5130 | LCSC | Q档 IR333C-A |  | https://www.lcsc.com/product-detail/C5130.html
22 | 2 | 2.2uH | L1,L2 | IND-SMD_L7.1-W6.5-P5.60 | 2.2uH | SPM6530T-2R2M | TDK | C76855 | LCSC | 2.2uH ±20% 8.4A |  | https://www.lcsc.com/product-detail/C76855.html
23 | 1 | GZ1608D601TF | L3 | L0603 |  | GZ1608D601TF | Sunlord(顺络) | C1002 | LCSC | 单路 0603磁珠 阻抗600Ω@100MHz |  | https://www.lcsc.com/product-detail/C1002.html
24 | 1 | E22-900M22S | LORA | WIRELM-SMD_E22-900M22S |  | E22-900M22S | EBYTE(亿佰特) | C411293 | LCSC | 868/915MHz贴片型LoRa模块 |  | https://www.lcsc.com/product-detail/C411293.html
25 | 1 | ICS-43434 | MIC | MIC-SMD_6P-L3.5-W2.7-P0.90-BL |  | ICS-43434 | TDK InvenSense(应美盛) | C5656610 | LCSC | 1.65V~3.63V |  | https://www.lcsc.com/product-detail/C5656610.html
26 | 1 | AO3400A | MSF_IR | SOT-23-3_L2.9-W1.3-P1.90-LS2.4-BR |  | AO3400A | YONGYUTAI(永裕泰) | C49195711 | LCSC | N沟道 耐压:30V 电流:5.8A |  | https://www.lcsc.com/product-detail/C49195711.html
27 | 1 | NCP18XH103F03RB | NTC | R0603 |  | NCP18XH103F03RB | muRata(村田) | C13564 | LCSC | 10kΩ 3380K 100mW |  | https://www.lcsc.com/product-detail/C13564.html
28 | 4 | 100kΩ | PD_MSF,R11,R14,R18 | R0603 | 100kΩ | 0603WAF1003T5E | UNI-ROYAL(厚声) | C25803 | LCSC | 100kΩ ±1% 100mW 厚膜电阻 |  | https://www.lcsc.com/product-detail/C25803.html
29 | 1 | HX PM2.54-1x3P ZC-Y | PIR | HDR-TH_3P-P2.54-V-F |  | HX PM2.54-1x3P ZC-Y | hanxia(韩下) | C22438153 | LCSC | 1x3P 间距:2.54mm 直插 |  | https://www.lcsc.com/product-detail/C22438153.html
30 | 1 | 15uH | QiCoil | CND-TEK-SMD_YX-A11-R501053-G0807 | 15uH | YX-A11-R500800-R0890 | CND-tek(磁联达) | C3003210 | LCSC | YX-A11-R500800-R0890 |  | https://www.lcsc.com/product-detail/C3003210.html
31 | 1 | BQ51013BRHLR | QIPowerRec | VQFN-20_L4.5-W3.5-P0.50-BL-EP_BQ24100RHLR |  | BQ51013BRHLR | TI(德州仪器) | C55663 | LCSC | 高度集成的无线接收器Qi（WPC V1.1）兼容电源 |  | https://www.lcsc.com/product-detail/C55663.html
32 | 11 | 10kΩ | R1,R5,R6,R7,R8,R15,R16,R17,R21,RESETB_PU,R_IO0 | R0603 | 10kΩ | 0603WAF1002T5E | UNI-ROYAL(厚声) | C25804 | LCSC | 厚膜电阻 10kΩ ±1% 100mW |  | https://www.lcsc.com/product-detail/C25804.html
33 | 4 | 33Ω | R2,R4,R9,R10 | R1206 | 33Ω | CR1206F433R0G | LIZ(丽智电子) | C102174 | LCSC | 厚膜电阻 33Ω ±1% 250mW |  | https://www.lcsc.com/product-detail/C102174.html
34 | 1 | 68Ω | R3 | R0603 | 68Ω | 0603WAF680JT5E | UNI-ROYAL(厚声) | C27592 | LCSC | 68Ω ±1% 100mW 厚膜电阻 |  | https://www.lcsc.com/product-detail/C27592.html
35 | 1 | 560kΩ | R12 | R0603 | 560kΩ | 0603WAF5603T5E | UNI-ROYAL(厚声) | C23203 | LCSC | 560kΩ ±1% 100mW 厚膜电阻 |  | https://www.lcsc.com/product-detail/C23203.html
36 | 3 | 100Ω | R20,R24,R25 | R0603 | 100Ω | 0603WAF1000T5E | UNI-ROYAL(厚声) | C22775 | LCSC | 100Ω ±1% 100mW 厚膜电阻 |  | https://www.lcsc.com/product-detail/C22775.html
37 | 1 | 470Ω | R22 | R0603 | 470Ω | 0603WAF4700T5E | UNI-ROYAL(厚声) | C23179 | LCSC | 470Ω ±1% 100mW 厚膜电阻 |  | https://www.lcsc.com/product-detail/C23179.html
38 | 2 | 1kΩ | R,R13 | R0603 | 1kΩ | CR0603FA1001G | LIZ(丽智电子) | C126900 | LCSC | 厚膜电阻 1kΩ ±1% 100mW |  | https://www.lcsc.com/product-detail/C126900.html
39 | 1 | 5.1kΩ | RT1 | R0603 | 5.1kΩ | 0603WAF5101T5E | UNI-ROYAL(厚声) | C23186 | LCSC | 厚膜电阻 5.1kΩ ±1% |  | https://www.lcsc.com/product-detail/C23186.html
40 | 1 | 30kΩ | RT2 | R0603 | 30kΩ | CR0603FA3002G | LIZ(丽智电子) | C100945 | LCSC | 厚膜电阻 30kΩ ±1% 100mW |  | https://www.lcsc.com/product-detail/C100945.html
41 | 2 | 5.1kΩ | R_CC5,R_CC6 | R0402 | 5.1kΩ | 0402WGF5101TCE | UNI-ROYAL(厚声) | C25905 | LCSC | 5.1kΩ ±1% 62.5mW 厚膜电阻 |  | https://www.lcsc.com/product-detail/C25905.html
42 | 2 | 22Ω | R_CC7,R_CC8 | R0402 | 22Ω | 0402WGF220JTCE | UNI-ROYAL(厚声) | C25092 | LCSC | 22Ω ±1% 62.5mW 厚膜电阻 |  | https://www.lcsc.com/product-detail/C25092.html
43 | 1 | 47nF | U4 | C0805 | 47nF | CC0805KRX7R9BB473 | YAGEO(国巨) | C107154 | LCSC | 47nF ±10% 50V |  | https://www.lcsc.com/product-detail/C107154.html
44 | 1 | TYPE-C-31-M-12 | USBC | USB-C_SMD-TYPE-C-31-M-12_1 |  | TYPE-C-31-M-12 | 韩国韩荣 | C165948 | LCSC | Type-C 母 卧贴 |  | https://www.lcsc.com/product-detail/C165948.html
45 | 1 | ME6211C33M5G-N | Voltage_Reg | SOT-23-5_L3.0-W1.7-P0.95-LS2.8-BL |  | ME6211C33M5G-N | MICRONE(南京微盟) | C82942 | LCSC | 3.3V 500mA 6V |  | https://www.lcsc.com/product-detail/C82942.html
46 | 1 | TPLP5907MFX-1.5 | Voltage_Reg1.5V | SOT-23-5_L2.9-W1.6-P0.95-LS2.8-BL |  | TPLP5907MFX-1.5 | TECH PUBLIC(台舟) | C49451987 | LCSC | 1.5V 300mA 5.5V |  | https://www.lcsc.com/product-detail/C49451987.html
47 | 1 | LP5907MFX-2.8/NOPB | Voltage_Reg2.8V | TSOT-23-5_L2.9-W1.6-P0.95-LS2.8-BL |  | LP5907MFX-2.8/NOPB | TI(德州仪器) | C186700 | LCSC | 2.8V 250mA 5.5V |  | https://www.lcsc.com/product-detail/C186700.html

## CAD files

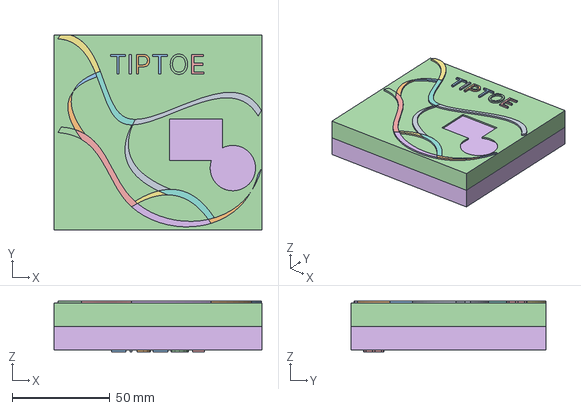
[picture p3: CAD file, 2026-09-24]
case/TIPTOE_Case.stp
106.3 x 99.8 x 26.0 mm

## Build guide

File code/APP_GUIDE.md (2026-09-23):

# TIPTOE app — build guide

This guide describes the phone app: what it has to do, how it should behave, and how it talks to the TIPTOE hardware. The exact wire format (UUIDs, framing, every JSON message and command) is in **[APP_PROTOCOL.md](APP_PROTOCOL.md)**. This file covers the rest: architecture, behaviour, screens, edge cases.

---

## 1. The system in one picture

```
 [Node 1] ─┐
 [Node 2] ─┼── LoRa (always, long range, small photos)
 [Node 3] ─┤   ESP-NOW (only when near the handheld AND its Wi-Fi is on, full-res photos)
           ▼
     [Handheld]  ← same TIPTOE PCB, role "handheld", carried by you
           │
           ├── BLE (always connected): alerts, status, small photos, commands
           └── Wi-Fi AP "TIPTOE-HH" (on demand): fast downloads, full-res photos
           ▼
       [Phone app]
```

Four facts shape the whole app:

1. **The app only talks to the handheld.** It never connects to outdoor nodes directly, with one exception: a node's walk-up maintenance mode (§9).
2. **Outdoor nodes sleep almost all the time.** They wake on motion or on a heartbeat timer (default every 30 min). A command for a node waits on the handheld until that node next wakes up. The app must make this delay visible, never hide it.
3. **The handheld is the source of truth.** It keeps the event archive and the latest status of every node. The phone keeps a local copy for speed and offline viewing, and syncs whenever it reconnects.
4. **The handheld doesn't know the time until the phone tells it.** Send the time on every connection.

---

## 2. Suggested stack (React Native)

| Need | Library | Notes |
|---|---|---|
| BLE | `react-native-ble-plx` | Works in bare RN or Expo with a dev build and config plugin. Values are base64. |
| Joining the handheld's Wi-Fi | `react-native-wifi-reborn` | Android `WifiNetworkSpecifier`, iOS `NEHotspotConfiguration` |
| Local database | `op-sqlite` / `expo-sqlite` (or WatermelonDB) | events, nodes, pending commands |
| Photo files | `react-native-fs` / `expo-file-system` | JPEGs on disk, DB stores paths |
| Notifications | `@notifee/react-native` | Local notifications, grouping, big-picture style, Android foreground service |
| Background BLE (Android) | foreground service via notifee | Keeps the connection alive when the app is backgrounded |
| State | Zustand / Redux Toolkit | One store fed by a single BLE service |

Architecture: one **`HandheldService`** singleton owns the BLE connection, the stream parser, the command/response matching and the Wi-Fi flow. Screens never touch BLE directly. They read from the store and DB and call service methods.

---

## 3. Permissions and platform setup

**Android**
- `BLUETOOTH_SCAN` (with `neverForLocation`) and `BLUETOOTH_CONNECT` on Android 12+. On Android ≤ 11, `ACCESS_FINE_LOCATION` instead.
- `POST_NOTIFICATIONS` (Android 13+).
- `FOREGROUND_SERVICE` + `FOREGROUND_SERVICE_CONNECTED_DEVICE` (Android 14+) for the background connection.
- `ACCESS_WIFI_STATE`, `CHANGE_WIFI_STATE`, `ACCESS_NETWORK_STATE`, `CHANGE_NETWORK_STATE`. Some Android versions also want location permission to connect to a specific Wi-Fi network.

**iOS**
- `NSBluetoothAlwaysUsageDescription`.
- Background mode **`bluetooth-central`**, so alerts keep arriving while the app is in the background. Use ble-plx `restoreStateIdentifier` so iOS can relaunch the app for BLE events.
- **Hotspot Configuration** capability (entitlement), for joining `TIPTOE-HH`.
- **`NSLocalNetworkUsageDescription`.** Without it, HTTP to `192.168.4.1` fails silently on iOS 14+.

---

## 4. Connection lifecycle

```
IDLE → SCANNING → CONNECTING → MTU → PAIRING → SUBSCRIBING → SYNCING → LIVE
          ↑                                                         │
          └────────────── RECONNECTING (backoff) ←──── disconnect ──┘
```

| Step | What to do |
|---|---|
| Scan | Filter on service UUID `7a1e0001-…`, name `TIPTOE-HH`. Remember the device id after the first pairing and reconnect to it directly. |
| Connect | `connectToDevice(id, { requestMTU: 517 })`. Also call `requestMTU` on Android. |
| Pairing | The handheld starts pairing itself, and the OS shows its own passkey dialog. The user enters the 6-digit PIN once, and the bond is remembered. The app only needs to tell the user the PIN is in the firmware's `secrets.h` (or printed on the handheld). |
| Subscribe | Monitor the TX characteristic `7a1e0003-…`. |
| Sync | (1) `time` with the phone's clock. (2) The handheld sends `handheld`, `nodes` and `wifi` by itself, so store them. (3) Catch up on events (§6). |
| Live | Handle pushed messages. Send `time` again every hour. |
| Reconnect | Exponential backoff: 1 s, 2 s, 5 s, 10 s, then every 30 s. **Reset the stream parser buffer on every disconnect.** |

**If pairing fails** (the user entered a wrong PIN, or the handheld was re-flashed and lost its bonds), the handheld drops the connection. Tell the user to "Forget TIPTOE-HH" in the phone's Bluetooth settings and try again.

---

## 5. BLE stream parser

Notifications are **one continuous byte stream**. A frame can span many notifications, and a notification can end one frame and start the next.

```ts
// frame = [type u8][len u32 LE][payload]
class StreamParser {
  private buf = new Uint8Array(0);

  push(chunk: Uint8Array, onFrame: (type: number, payload: Uint8Array) => void) {
    this.buf = concat(this.buf, chunk);
    while (this.buf.length >= 5) {
      const type = this.buf[0];
      const len = this.buf[1] | (this.buf[2] << 8) | (this.buf[3] << 16) | (this.buf[4] << 24);
      if (len < 0 || len > 4_000_000) { this.reset(); return; }   // desync guard
      if (this.buf.length < 5 + len) return;                       // wait for more bytes
      onFrame(type, this.buf.subarray(5, 5 + len));
      this.buf = this.buf.slice(5 + len);
    }
  }
  reset() { this.buf = new Uint8Array(0); }
}

function onFrame(type: number, p: Uint8Array) {
  if (type === 1) handleJson(JSON.parse(utf8Decode(p)));
  else if (type === 2) {
    const seq = p[0] | (p[1] << 8) | (p[2] << 16) | (p[3] << 24);
    const full = p[4] === 1;
    saveJpeg(seq, full, p.subarray(5));   // write to disk, update DB, refresh UI
  }
}
```

Use a growable buffer, or a list of chunks plus a total length, rather than concatenating on every notification. Full-res images over BLE can be 300 KB+.

**Commands and responses.** Give every command a `rid`: an incrementing number. Keep a map `rid → {resolve, reject, timeout}`. Responses (`t:"resp"`, and list replies like `nodes`/`events`) echo the `rid`. Time out after 5 s (30 s for `get_image`). One write per command, **write-with-response**, max 512 bytes.

---

## 6. Local data model and sync

```sql
handheld(id, fw, soc, vbat_mv, charge, ntc, wifi, time_synced, fs_free_kb, lora_budget_ms, updated_at)

nodes(node_id PK, name, last_seen_at, rssi, snr, via, armed, soc, vbat_mv, charge, ntc, temp_c,
      qi_mv, hw_ok, fw, event_count, fs_free_kb, heartbeat_min, cooldown_s, jpeg_quality,
      framesize, ir_mode, ir_luma, pending_count, status_json)

events(seq PK, node_id, event_id, trigger, time, received, ir, sound_peak_db, sound_rms_db,
       luma, soc, width, height, via, rssi, has_image, full, bytes,
       small_path NULL, full_path NULL, hires_on_node, camera_failed, no_budget, seen BOOL)

pending(id, node_id, cmd, key, value, created_at)   -- the app's mirror of what's queued
```

- **Node names are app-only.** The firmware only knows numeric IDs (1–254). Let the user name them ("Garden", "Gate") and store the names locally.
- **`seq` is the key for events.** It's the handheld's archive id. `event_id` is per-node and can repeat after a node is reset.
- **Catch-up after reconnecting:** request `{"cmd":"events","limit":50}` and insert anything newer than your highest stored `seq`. If all 50 are new, page with `before` = the oldest seq you received, until you reach known ground. Then request `get_image` (small) for recent events that have `has_image` but no `small_path`, limited to the last ~20 to save time.
- **Archive pruning:** the handheld deletes its oldest events when its flash fills up. The phone may keep them longer. Mark events whose `seq` is no longer on the handheld as "phone only".

---

## 7. Screens

**Onboarding**
1. Explain the system in two sentences, then request permissions.
2. Scan for and pair the handheld (PIN).
3. List the nodes the handheld already knows about, and let the user name each one.
4. Set up notifications.

**Home / dashboard**
- Handheld card: battery, charging, connection state, Wi-Fi on/off.
- A card per node:
  - name, online state (§8.3)
  - battery % and charging icon
  - signal bars from RSSI (≥ −90 good, −90…−110 ok, < −110 weak)
  - last seen ("4 min ago")
  - armed toggle
  - a "motion" badge (§8.1)
  - pending-command count with an ETA
- Most recent events strip with thumbnails.

**Timeline**
- All events, newest first, filterable by node and date.
- Thumbnail, node name, time, trigger (motion / snapshot / button), IR icon, sound level, a "full-res available" badge.
- Unseen events highlighted.

**Event detail**
- Photo, pinch-to-zoom.
- Metadata: time, node, trigger, IR on/off, sound peak/RMS (show dBFS as a simple meter), light level, battery at the time, received via LoRa/ESP-NOW, RSSI.
- Actions: **Get full-res** (§8.5), share, delete (`delete_event`), "Take a new snapshot from this node".

**Node detail**
- Full status: battery, voltage, charge state, Qi input voltage, charger temperature state, temperature, firmware, uptime, free storage, hardware health (decode `hw_ok`, §8.4).
- Config editor: armed, heartbeat, cooldown, JPEG quality, photo size, IR mode and threshold, audio length, TX power, send image, keep full-res locally, B/W under IR. Each field shows its **confirmed** value and any **pending** value (§8.2).
- Actions: snapshot, request status, reboot, maintenance mode, clear node storage, cancel pending commands.
- The node's event history.

**Handheld**
- Battery, time sync, LoRa duty-cycle budget left, free storage, firmware.
- Wi-Fi on/off.
- "Forget / re-pair" help.

**Settings**
- Notification preferences per node (all / motion only / none, quiet hours).
- Units, how long to keep photos on the phone, a debug log view (raw frames), export.

---

## 8. Behaviour rules

### 8.1 Motion alerts and notifications
- A **`event`** message is the alert. It arrives within about a second of the PIR firing, before the photo.
  - Show a notification immediately: "Motion — Garden", with IR/sound info in the body.
  - Group notifications per node. Use a stable notification id per node plus event, so it can be updated later.
- When the matching **`image`** arrives (same `node` + `event_id`), update that notification to the big-picture style with the thumbnail. For LoRa photos that's roughly 10–20 s later; for ESP-NOW, a few seconds.
- If `camera_failed` is set, say so ("Motion — camera error").
- If `no_budget` is set, say "photo kept on the node (radio limit reached)".
- **Motion badge:** a node shows "motion" for 60 s after its last `event`. During continuous motion, nodes send extra header-only events at most every 10 s, which keeps the badge on.
- Throttle notification sound: at most one alert sound per node per minute. Later events update the existing notification silently.

### 8.2 Commands are queued, not instant
- After a `set`/`snapshot`/etc., show the command as **pending** with an ETA, for example "Applies at next check-in, ≈ 12 min". Estimate it as `last_seen + heartbeat_min − now` (or "within 1 min" if a motion event is likely).
- The handheld pushes **`pending`** counts. When a node's count drops to 0 **and** a fresh `status` arrives with the new values in `config`, mark the change **confirmed**. Nodes send a status right after applying settings.
- For settings, update the UI optimistically but in a distinct "pending" style, and roll it back if a later `status` shows the old value after the pending count reached 0.
- **`snapshot`:** the result arrives as a normal `event` with `trigger:"snapshot"`. Link it to the request in the UI ("Snapshot from Gate arrived").
- **`cancel`** clears everything queued for a node. Offer it on the pending indicator.
- Suggest lowering `heartbeat_min` (e.g. 5–10) in the UI if the user wants faster control, and say that it costs battery.

### 8.3 Online / offline
- A node is **online** if `age_s < heartbeat_min × 60 × 2.5 + 60`.
- Otherwise it's **late**. After 4 missed heartbeats it's **offline**; notify once.
- A `hello_node` message means the node just powered up or rebooted. Show a subtle notice in its log ("Gate restarted").

### 8.4 Health warnings (per node, shown on the card and as optional notifications)

| Condition | Message |
|---|---|
| `soc < 20` and not charging | Battery low |
| `soc < 5` | Battery critical — node has stopped watching |
| `ntc` = `cold` / `hot` | Too cold/hot to charge — charging paused |
| `ntc` = `warm` / `cool` | Charging at reduced rate (temperature) |
| `qi_mv > 4000` | On Qi pad (charging source present) |
| `hw_ok` missing bit 8 | Camera problem |
| `hw_ok` missing bit 16 | Microphone problem |
| `hw_ok` missing bit 32 | Camera power rail problem |
| `hw_ok` missing bits 1/2/4/64 | Board fault (expander / charger / fuel gauge / flash) |
| `fs_free_kb < 1500` | Node storage nearly full (oldest local photos being deleted) |
| RSSI < −115 or SNR < −10 | Weak link — consider moving the node or handheld |

`hw_ok` bits: 1 expander, 2 charger, 4 fuel gauge, 8 camera, 16 mic, 32 camera power rail, 64 flash.

The handheld itself sends a `warning` before it shuts down on a critical battery. Show that as a high-priority notification.

### 8.5 Full-resolution photos
There are three ways a full-res photo can reach you:

1. **Already on the handheld** (`full:true`, sent over ESP-NOW). Two ways to fetch it:
   - **Over Wi-Fi (fast, preferred):** `wifi on` → join `TIPTOE-HH` → `GET /img?seq=N&full=1` → save → leave the network → `wifi off`.
   - **Over BLE (no network switch, slower):** `get_image` with `full:true`, and show progress from bytes received versus `bytes` in the response. That's roughly 5–20 s for 200–350 KB.
2. **Only on the node** (`hires_on_node:true`, sent over LoRa small). The current firmware can't pull an old full-res photo from a node remotely. Tell the user: "The full photo is stored on the node. Turn on Near mode and walk up to the node, or open its maintenance mode." Future photos arrive full-res automatically while Near mode is on.
3. **Near mode:** a toggle that switches the handheld's Wi-Fi on. While it's on:
   - nodes close to the handheld send **full-res photos over ESP-NOW** automatically
   - the handheld uses ~100 mA more, so show a warning
   - it turns itself off after 10 min without activity; reflect that in the UI when the `wifi` message says `on:false`.

### 8.6 Joining the handheld's Wi-Fi
- Get the SSID and password from the `wifi` message. Don't hard-code them.
- **Android:** request the network with `WifiNetworkSpecifier`, then **bind the app's process to that network** so HTTP goes to `192.168.4.1` while mobile data still carries the internet. Release the binding when done.
- **iOS:** `NEHotspotConfiguration` with `joinOnce: true`. The user sees a system prompt the first time. The Local Network permission must be granted.
- Always send `wifi off` after a transfer, to save the handheld's battery.

### 8.7 Time
- Send `{"cmd":"time","unix":<seconds>}` on every connect and every hour.
- Event `time` is 0 if the node had never been synced when the event happened. In that case, show `received` (handheld time) instead, marked "≈".

---

## 9. Talking to a node directly (maintenance mode)

This is for setup, diagnostics, firmware updates, and pulling a node's own archive (full-res photos and audio).

- Trigger it with the `maintenance` command (applies at the next check-in) or by pressing the node's BOOT button.
- The node opens Wi-Fi AP **`TIPTOE-<node id>`** (password `TIPTOE_MAINT_AP_PASS`), at `http://192.168.4.1`. It closes after 10 minutes idle.
- Node endpoints:

| | |
|---|---|
| `GET /api/status` | full status + config JSON |
| `GET /api/events` | `[{id, meta, hi, wav}]` (node-local event ids) |
| `GET /ev/<id>.jpg`, `/ev/<id>_hi.jpg`, `/ev/<id>.wav` | small photo, full-res photo, audio |
| `GET /snapshot.jpg?ir=0|1` | live photo (1024×768) |
| `POST /api/config` (form fields, same keys as `set`) | change settings immediately |
| `POST /api/exit` | close maintenance mode, node goes back to sleep |
| `POST /update` (multipart `fw`) | OTA firmware update |

The app can offer a **"Visit node"** flow: send `maintenance` → wait for the node to check in → join `TIPTOE-<id>` → browse the node's archive → import full-res photos and audio into the phone's event records (match by node + `event_id`) → `POST /api/exit`.

---

## 10. Errors and edge cases

| Situation | Behaviour |
|---|---|
| `resp` with `ok:false` | Show the `error` field. For `set`, the key name or value was rejected. |
| No response within the timeout | Mark the command failed and allow retry. Don't assume it wasn't queued: check `pending` counts after reconnecting. |
| BLE drops mid-image | Parser reset. Re-request with `get_image` on reconnect. |
| Handheld rebooted | `uptime_s` resets. Pending commands on the handheld are **lost** (they live in RAM), so re-send anything still pending in the app's mirror after checking `pending` counts. |
| Event received twice | Use `seq` as the unique key. `image` and `events` can overlap after a reconnect. |
| Node reset its event counter | `event_id` may repeat for a node. Always key on `seq`. |
| Handheld flash full | The oldest events are deleted there. The phone keeps its own copies. |
| Duty-cycle budget low | Show `lora_budget_ms` on the handheld screen. When exhausted, nodes keep photos locally and send `no_budget` events. |

---

## 11. Security notes

- **BLE:** passkey pairing with MITM protection; everything is encrypted after bonding. Keep the PIN out of the app bundle; the user types it into the OS dialog.
- **Wi-Fi passwords** come over the encrypted BLE link. Don't log them, and don't store them longer than needed.
- **Unit-to-unit traffic** is AES-GCM with a shared network key that's baked into firmware. The app never sees it.

---

## 12. Developing without hardware

Build a **mock handheld** inside the app (debug-only): a fake `HandheldService` that emits the same framed stream. Example payloads from APP_PROTOCOL.md:
- `handheld` and `nodes` on connect
- a `status` every 30 s
- an `event` followed ~10 s later by an `image` plus a type-2 frame with a bundled test JPEG
- `pending` updates after commands

This lets you build every screen and the notification logic before the boards exist.

Test checklist once hardware is on the desk:
- [ ] First pairing, then reconnect after the app is killed, after Bluetooth is toggled, and after the handheld reboots
- [ ] Motion alert with the phone locked (Android foreground service / iOS background mode)
- [ ] A LoRa photo arrives and decodes; the full-res pull works over both BLE and Wi-Fi
- [ ] Commands: pending → delivered → confirmed by status; cancel works
- [ ] Near mode: a node near the handheld sends full-res over ESP-NOW; Wi-Fi auto-off after 10 min is reflected in the UI
- [ ] Catch-up sync after the phone was out of range for hours
- [ ] Walk-up maintenance flow and OTA

---

## 13. Not in the firmware yet (possible later additions)

- Remotely fetching an **old** full-res photo from a node on demand. Today that needs Near mode at event time, or maintenance mode.
- Node names stored on the handheld (today they're app-only).
- OTA for outdoor nodes pushed from the app through the handheld.
- A handheld settings command (Wi-Fi idle timeout, BLE PIN change).
- Persisting pending commands on the handheld across reboots.

If the app needs any of these, they're firmware changes. Note the need and they can be added.

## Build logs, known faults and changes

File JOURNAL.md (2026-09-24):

title: "TIPTOE"
author: "Cosmin Mare"
description: "Multi-unit surveillance system with motion detection, night vision and multiple communication modes. Deployable and waterproof , it's the perfect awareness device and it comes with an app for alerts, photo snapshots and video + audio streaming."
created_at: "2026-06-28"
---

# July 5: Started working on the PCB

Started the project in easyEDA, wired a basic usb C to be able to flash the ESP, wired IO0 pin and reset pin and learned how to do all of these. Also, I asked for help in the slack (more like for a sanity check) and someone actually helped :D and told me that i wired a capacitor wrong and I figured it out by myself why it was wired wrong!! Anyways, I'm super happy with my progress given that it's my first time working with actual components on a PCB by myself.

I've also started watching basically the whole "The Engineering Mindset" channel on youtube but I'm not adding that to the time spent lmao
Screenshot 2026-07-05 at 9 54 11 PM

**Total time spent: 2 hours**

# July 12: Almost finished wiring the Power stuff

Wired the Qi Receiver, caught some mistakes such as a 100nF capacitor that should've actually been 10nF. Wired the whole BQ25895 battery charger, added a MAX17048 fuel gauge, then when wanting to wire the ALRT# pin, I realized I don't actually have any more free GPIO pins on the ESP (did some calculations bc I haven't yet palced the components) so I added a PCF8574 IO Expander. Changed the generic ESP module I was working with to an actual model that I can order (N16R8). I'm again really happy with the progress and I feel like I learned A LOT about wiring a PCB and power management and GPIO management.

SCH_Schematic1_1-P1_2026-07-12

**Total Time spent: 3 hours**

# July 17: Power tree done

Found a bunch of stuff that I wired wrong such as the TPS63020 FB loop wired wrong, its PG was tied to ground so you couldn't read the status, the I2C bus wasn't actually tied correctly and I had to learn about what it actually is and it's so interesting how little pieces of sillicon are so smart man. Anyways, there's also other stuff that was tied wrong and I had to check a bunch of datasheets and checked every pin, every connection and every wire and hopefully it's good now, bc if I do anything wrong here I'll basically have PCB that aren't gonna be able to get powered. and holy moly this schematic is getting huge

SCH_Schematic1_1-P1_2026-07-16

**Total Time spent: 2 hours**

# July 19: Gang I finished the schematic

Ok so it turns out once you actually understand what you're doing stuff gets easier + wiring power and qi coils is hard asf if that's the first pcb related thing you do and idk why I started with that but it seemed like the correct start given that without power nothing happens? anyways, I wired the LoRa, the camera, the mic and the IR LEDs and am completely done with the schematic. I checked and double checked everything, I did some mistakes on some resistors, I forgot about some wires and capacitors, but it's all good now hopefully (I sent the netlist to claude opus 4.8 and it said we're good so I hope we are lmao). I'll also send to forge channel to triple check but Idk if anyone's gonna look at everything💀. anyways, it was actually fun to do this, and I can't wait to do the layout for the actual PCB. Oh yeah I split everything up so now i have multiple pages! They got uploaded in the wrong order but it's 1am and I'm not changing it to the correct order rn i've done enough💀

SCH_Schematic1_7-IR_2026-07-19
SCH_Schematic1_6-Mic_2026-07-19
SCH_Schematic1_5-PIR_2026-07-19
SCH_Schematic1_4-Camera_2026-07-19
SCH_Schematic1_3-LoRa_2026-07-19
SCH_Schematic1_2-Power Tree_2026-07-19
SCH_Schematic1_1-Main Board_2026-07-19

**Total Time spent: 3 hours**

# July 24: I thought the hard part is over...

Pretty dramatic title, but I realized that laying out a pcb is really hard and confusing😭. I spent at least 1 hour standardizing the parts and making sure I don't have 1000 different footprints. Then after doing that I synced the schematic to the pcb instead of the pcb to the schematic and lost all progress bc I didn't realize so I had to do it again. Then I forgot about a bunch of capacitors and I had like 100 different sizes. Anyways, I went on the PCB tab and I almost fainted bc there's a bagilion lines connecting everything and I was extremely overwhelmed by that. Needless to say, I spent a bunch of time making sure everything is laid out properly and now I'm gonna start routing ts

PCB_PCB1_2026-07-24

**Total Time spent: 4 hours**

# July 26: I started loving PCB design

So update from last time, I routed everything in that photo, decided that it's not compact enough so I redid the layout and the routing and honestly it wasn't even boring. it's like those games that you have colored circled and you need to connect them lmao. anyways, not that much else to say? except I asked a few questions on slack and people were really helpful, that's what prompted the redesign of the layout and yeah I'm looking forward to customizing this a bit, and submitting for review to see if it works. First images are v1 and the next are v2. and wow time passed so fast yesterday I started at like 3pm and in like 5 minutes it was 10pm
Finished V1
Screenshot 2026-07-25 at 8 27 22 PM
PCB_PCB1_1_2026-07-26
PCB_PCB1_1_2026-07-26_top
Screenshot 2026-07-26 at 11 11 00 AM
Screenshot 2026-07-26 at 11 11 16 AM
Screenshot 2026-07-26 at 11 12 51 AM

**Total Time spent: 5.5 hours**

# July 26 part 2: I spent 2h looking for PCB prices

Expensive af everywhere... honestly idk what to do, I'll probably have to go full price with easyeda standard double side and then pray that the pcb works bc I don't think I can solder everything... idk, we'll see. I have a hot air gun but I'm kinda afraid I'm gonna melt stuff with it😭. anyways, here's some insane quotes: (3rd ss is just ONE SIDE, 4th one shipping is on the least expensive setting and doesnt factor component cost, i'm actually gonna rob a bank)


Screenshot 2026-07-26 at 3 16 01 PM
Screenshot 2026-07-26 at 3 16 17 PM
Screenshot 2026-07-26 at 3 16 52 PM

**Total Time spent: 2 hours**

# July 29: Routing yet another version

I replaced everything to be on one layer and rerouted everything yet again, then looked again for pricing, I had to change some components because they weren't being stocked anymore by jlcpcb and then route them again. But it's finally over and I'm done with the first prototype and ready to get it printed.
PCB_PCB1_2_2026-07-29top
PCB_PCB1_2_2026-07-29bottom

**Total Time spent: 2 hours**

# September 20: Why did nobody tell me about Plasticity????

first of all, here's the lapse link: https://lapse.hackclub.com/timelapse/ObhvUft3RnZe

So i started working again on this project bc I wanna go to hackaday supercon, and last time I stopped working on it bc i dreaded the 3d modelling. I really like 3d modelling in blender and I REALLY HATE 3d modelling in onshape or fusion. So today I started a lapse session and wanted to get past my fears and use onshape. First I had to remember if there was any parts I postponed finding and stuff like that so i checked easyeda and jlcpcb and apparently I did place and select all the correct parts. So i tried exporting the STEP file and import it into onshape and I spent a bit of time on importing it bc it kept giving me an error. Next, I reasearched the error a bit and asked claude but i wasn't able to fix it so then i searched what other software i could use that's similar to blender(kill two birds with one stone, fix the error and use a better software) and i found plasticity and I tested it to see how it works in this session and I think I know what I have to do in the next one to start work on the case. But I love plasticity and rn I feel like 3d modelling won't be such a pain anymore, but we'll see :)



**Total Time spent: 1.3 hours**

# September 22: So i got some feedback...

I like doing these dramatic titles lmao it feels like a series

anyways I'm rerouting my pcb the 4th time........... also I did some more work for the case (I figured out how to find 3d models for pcbs like the PIR sensor i'll be using) 
but yeah I'm mainly rerouting my pcb and moving some stuff around. it's like the 4th rerouting I'm doing and I hope last one. also tidied up the repo.
here's the lapses: https://lapse.hackclub.com/timelapse/rKCQ60doAXuo, https://lapse.hackclub.com/timelapse/cbj4ek7eiZbi, https://lapse.hackclub.com/timelapse/IZojvrlUvxLE, https://lapse.hackclub.com/tIimelapse/_HY0aCUIuGnW

okay I'm editing this again, it's still september 22 and I'm done w the case!! It's been a long day and it's 8pm and I'm going to the gym to relax a bit. It's been fun designing the case in plasticity but i'm not looking forward to doing any more 3d modelling for at least 2 days lmao

Screenshot 2026-09-22 at 7 49 22 PM
PCB_PCB4_2026-09-22

**Total Time spent: 6 hours**

# September 23: Final Stretch

I asked claude to flag anything bad in the pcb and i gave it the netlist and it flagged that I didn't do the power the right way for the camera bc it actually takes in 2.8V and also 1.5V through another pin, which i had no idea, so i made 2 LDOs, also there were other things wrong like the temp sensing for the battery charger IC, current too low for the IR LEDs. so i spent some time fixing those and then placing and routing everything on an already crammed board which was pretty painful ngl. also, I quickly made a firmware and an app with AI bc I don't have the devices and idk I feel like I already know how this works and how to code it and I understood pretty much everything. I'm gonna upload the builds for the app for ios and android and I think I'm done for today, and pretty much done with the project. Tomorrow I'll do some 3d renders and I'll see if I'll take this any further making a custom handheld PCB to talk to the phone or even have its own screen, or just have one of the board be the handheld. I had a lapse session but i stopped it after an hour this morning bc I had to run some errands and i was on and off for like a couple of hours and then I didn't turn it on when I started reoruting the pcb, but I think it's fine.

Screenshot 2026-09-23 at 9 17 27 PM

**Total Time Spent: 3.5 hours**

# September 24: Ready to ship!

I did some last minute changes recommended to Madhav (tysm for reviewing the PCB), I organized and exported everything, I bought plasticity indie license bc it's the best 3d modelling/cad software, I then set up a scene in blender and did some lighting and some renders, I had to tweak the case a bit bc i moved the IR leds around, but everything is now done and updated. I honestly don't know how much this took bc it was a bunch of smaller tasks that I did throughout the day so I'll approximate on the lower end, but i know the setup in blender took like an hour.

Top white
Top white nocase
Top Right
Top Right White
Top Right white nocase
Top Right nocase
Front
Front White

**Total Time Spent: 2 hours**

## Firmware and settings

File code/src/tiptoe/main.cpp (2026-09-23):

// TIPTOE firmware entry point. role=handheld -> handheld::run() (never returns).
// role=node (default) -> wake, do one job, deep sleep.
//
// Wake sources
//   cold boot  -> hardware init, optional USB console, HELLO uplink, PIR warm-up (60 s)
//   PIR (IO3)  -> event: photo (auto IR) + sound level, archive to flash, send over LoRa
//   BOOT (IO0) -> Wi-Fi maintenance mode (web UI, archive, OTA)
//   timer      -> heartbeat status uplink (downlink commands arrive in its reply window)
#include <Arduino.h>
#include <driver/gpio.h>
#include <driver/rtc_io.h>
#include <esp_sleep.h>
#include <esp_task_wdt.h>
#include "app.h"
#include "camera.h"
#include "board.h"
#include "config.h"
#include "console.h"
#include "expander.h"
#include "handheld.h"
#include "link.h"
#include "maintenance.h"
#include "power.h"
#include "protocol.h"

static constexpr uint32_t PIR_WARMUP_S = 60;       // HC-SR501 settles after power-up
static constexpr uint32_t PIR_BUSY_RECHECK_S = 5;  // PIR still high -> re-check instead of ext0
RTC_DATA_ATTR static uint32_t rtc_next_heartbeat = 0;

static void scheduleHeartbeat() {
  uint32_t min = config::cfg.heartbeat_min;
  if (app::batteryCritical()) min = max<uint32_t>(min, 180);
  rtc_next_heartbeat = lora::monoSeconds() + min * 60;
}

[[noreturn]] static void goToSleep() {
  lora::sleep();
  power::voutOff();
  expander::write(xbit::IR_LED, false);

  // Hold the buck-boost off and NSS high through deep sleep.
  digitalWrite(pins::VOUT_EN, LOW);
  gpio_hold_en((gpio_num_t)pins::VOUT_EN);
  gpio_deep_sleep_hold_en();

  uint32_t now = lora::monoSeconds();
  uint32_t sleepS = rtc_next_heartbeat > now ? rtc_next_heartbeat - now : 1;
  bool pirHigh = digitalRead(pins::PIR);
  bool armPir = config::cfg.armed && app::pirWarm() && !app::batteryCritical();

  if (!app::pirWarm()) sleepS = min<uint32_t>(sleepS, PIR_WARMUP_S);
  if (armPir && pirHigh) sleepS = min<uint32_t>(sleepS, PIR_BUSY_RECHECK_S);   // wait for PIR hold time to end
  else if (armPir) esp_sleep_enable_ext0_wakeup((gpio_num_t)pins::PIR, 1);
  esp_sleep_enable_ext1_wakeup(1ULL << pins::BTN_BOOT, ESP_EXT1_WAKEUP_ANY_LOW);
  esp_sleep_enable_timer_wakeup(uint64_t(max<uint32_t>(sleepS, 1)) * 1000000ULL);

  log_i("sleep %us (pir %s)", sleepS, armPir ? (pirHigh ? "busy" : "armed") : "off");
  Serial.flush();
  esp_deep_sleep_start();
}

static void handleAfterReply() {
  app::processPending();
  if (app::pending.reboot) ESP.restart();
  if (app::pending.maintenance) {
    app::pending.maintenance = false;
    esp_task_wdt_delete(nullptr);
    maintenance::run();
    esp_task_wdt_add(nullptr);
  }
}

void setup() {
  // First thing: stop UART0 TX (GPIO43) from driving 3.3 V into the unpowered camera SCCB line.
  camera::releasePins();
  Serial.begin(115200);
  Serial.setTxTimeoutMs(0);   // don't block when no USB host is attached

  // Anything hanging (camera, radio, I2C) must not flatten the battery.
  esp_task_wdt_init(90, true);
  esp_task_wdt_add(nullptr);

  esp_sleep_wakeup_cause_t cause = esp_sleep_get_wakeup_cause();
  bool cold = cause == ESP_SLEEP_WAKEUP_UNDEFINED;
  app::initHardware(cold);

  if (config::cfg.role == ROLE_HANDHELD) {
    if (cold && console::offer()) {
      esp_task_wdt_delete(nullptr);
      console::run();
      esp_task_wdt_add(nullptr);
      if (config::cfg.role != ROLE_HANDHELD) ESP.restart();
    }
    handheld::run();
  }

  switch (cause) {
    case ESP_SLEEP_WAKEUP_EXT0:   // PIR
      if (config::cfg.armed) app::runEvent(proto::TRIG_PIR);
      handleAfterReply();
      break;

    case ESP_SLEEP_WAKEUP_EXT1:   // BOOT button
      esp_task_wdt_delete(nullptr);
      maintenance::run();
      esp_task_wdt_add(nullptr);
      break;

    case ESP_SLEEP_WAKEUP_TIMER: {
      uint32_t now = lora::monoSeconds();
      if (!app::pirWarm() && now - app::coldBootMono() >= PIR_WARMUP_S) app::setPirWarm();
      // PIR was still high when we slept (hold time / continuous motion): treat as ongoing motion.
      if (config::cfg.armed && app::pirWarm() && !app::batteryCritical() && digitalRead(pins::PIR)) {
        app::runEvent(proto::TRIG_PIR);
        handleAfterReply();
      }
      if (now + 2 >= rtc_next_heartbeat) {
        app::sendStatus(proto::UP_STATUS, cause);
        scheduleHeartbeat();
        handleAfterReply();
      }
      break;
    }

    default: {                    // cold boot / reset button / brown-out
      if (console::offer()) {
        esp_task_wdt_delete(nullptr);
        console::run();
        esp_task_wdt_add(nullptr);
      }
      app::sendStatus(proto::UP_HELLO, (uint8_t)esp_reset_reason());
      scheduleHeartbeat();
      handleAfterReply();
      break;
    }
  }
  if (rtc_next_heartbeat == 0) scheduleHeartbeat();
  goToSleep();
}

void loop() {}

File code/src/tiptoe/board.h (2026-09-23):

// TIPTOE rev1 pin map — derived from Netlist_Schematic1_2026-09-22.net
#pragma once
#include <stdint.h>

#define FW_MAJOR 1
#define FW_MINOR 2

namespace pins {
// Main I2C bus (10k pull-ups R6/R7 to 3V3): PCF8574 (0x20), BQ25895 (0x6A), MAX17048 (0x36).
constexpr int I2C_SDA = 8;
constexpr int I2C_SCL = 9;
constexpr int EXP_INT = 38;          // PCF8574 INT# (R17 pull-up). Not an RTC pin -> no deep-sleep wake.

constexpr int VOUT_EN = 2;           // TPS63020 EN (R18 100k pull-down). VOUT feeds camera LDOs, mic, IR LEDs.
constexpr int PIR = 3;               // HC-SR501 OUT, active high (RTC GPIO -> ext0 wake)
constexpr int BTN_BOOT = 0;          // IO0 button, active low (RTC GPIO -> ext1 wake)

// E22-900M22S (SX1262)
constexpr int LORA_MOSI = 10;
constexpr int LORA_MISO = 11;
constexpr int LORA_SCK = 12;
constexpr int LORA_NSS = 13;
constexpr int LORA_BUSY = 14;
constexpr int LORA_DIO1 = 21;

// ICS-43434 I2S mic (L/R tied to VOUT -> right slot)
constexpr int MIC_SCK = 1;
constexpr int MIC_WS = 47;
constexpr int MIC_SD = 48;

// OV3660 on 24-pin FPC. Rails: CAM 2.8V (AVDD via bead, DOVDD) and CAM 1.5V (DVDD), both
// LDOs fed from VOUT. PWDN hard-wired to GND, RESETB pulled up to CAM 2.8V with an RC delay.
// SCCB on its own pins (UART0 TXD0/RXD0) via 1k series R, 4.7k pull-ups to CAM 2.8V.
constexpr int CAM_SDA = 43;   // TXD0 — driven by ROM/boot on every reset; released to input in setup()
constexpr int CAM_SCL = 44;   // RXD0
constexpr int CAM_XCLK = 39;
constexpr int CAM_PCLK = 16;
constexpr int CAM_VSYNC = 42;
constexpr int CAM_HREF = 41;
constexpr int CAM_D9 = 40;   // Y9
constexpr int CAM_D8 = 18;
constexpr int CAM_D7 = 17;
constexpr int CAM_D6 = 15;
constexpr int CAM_D5 = 6;
constexpr int CAM_D4 = 4;
constexpr int CAM_D3 = 5;
constexpr int CAM_D2 = 7;    // Y2
}  // namespace pins

// PCF8574 bit assignment
namespace xbit {
constexpr uint8_t GAUGE_ALRT = 0;    // in, MAX17048 ALRT# (active low)
constexpr uint8_t IR_LED = 2;        // out, AO3400 gate via 100R (high = IR on)
constexpr uint8_t VOUT_PG = 3;       // in, TPS63020 PG (high = good)
constexpr uint8_t LORA_NRST = 4;     // out, SX1262 reset (low = reset)
constexpr uint8_t LORA_RXEN = 5;     // out
constexpr uint8_t LORA_TXEN = 6;     // out
// P1, P7 unconnected
}  // namespace xbit

namespace i2caddr {
constexpr uint8_t EXPANDER = 0x20;
constexpr uint8_t GAUGE = 0x36;
constexpr uint8_t CHARGER = 0x6A;
constexpr uint8_t CAMERA = 0x3C;    // on the camera's own SCCB bus (GPIO43/44)
}  // namespace i2caddr

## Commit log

2026-07-05 Add journal entry for July 5 on PCB development
    Documented progress on PCB work and learning resources.
2026-07-12 Update JOURNAL.md with July 12 progress
    Documented progress on wiring and components for the project, including issues encountered and solutions implemented.
2026-07-17 Update JOURNAL.md with wiring corrections and time logs
    Documented progress on wiring corrections and schematic updates.
2026-07-18 Document July 19 schematic completion and challenges
    Added detailed entry for July 19, documenting the completion of the schematic and challenges faced during the process.
2026-07-24 Update JOURNAL.md with July 24 entry
    Added journal entry detailing challenges faced during PCB layout and time spent on standardizing parts and routing.
2026-07-26 Document PCB design progress for July 26
    Added a new entry about PCB design progress and time spent.
2026-07-26 Document PCB price search and time spent
    Added a new entry detailing PCB price search and time spent.
2026-07-29 Update JOURNAL.md with July 29 entry
    Documented the completion of the first prototype and routing changes.
2026-07-29 for review
    [empty.stl]
2026-07-29 add schematics
2026-09-20 Update JOURNAL.md with September 20 entry
    Added a new entry about feedback received and PCB rerouting.
2026-09-22 Revise journal entry for September 22
    Updated journal entry with new date and additional details about PCB rerouting and case work.
2026-09-22 tidy up
    [BOM.csv, BOM.xlsx, empty.stl]
2026-09-22 Update README with new images
    Added additional images of PCB and schematics to README.
2026-09-22 Update PCB image in README
    Replaced an old PCB image with a new 3D PCB image.
2026-09-22 Update PCB routing details and add timelapse link
    Added a new timelapse link and tidied up the repository.
2026-09-22 Revise JOURNAL.md with new links and time spent
    Updated journal entry with additional links and reflections on case design.
2026-09-23 Add firmware, phone app, and release builds under code.
    The phone needs installable Android and iOS packages next to the board firmware, without mixing them into the PCB files.
    [partitions_node.csv]
2026-09-23 Update JOURNAL.md with final project notes
    Documented final updates and challenges faced during the project, including power supply adjustments and firmware development.
2026-09-24 update project files
    [BOM.csv, TIPTOE_Case.stp, TiptoeCase_NO_PCB.stl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]
2026-09-24 Finalize PCB and complete 3D renders
    Made final adjustments to the PCB based on feedback, organized files, purchased a software license, and completed rendering in Blender. Estimated time spent on various tasks throughout the day.
2026-09-25 Enhance README with assembly and BOM details
    Added assembly instructions and bill of materials to README.
